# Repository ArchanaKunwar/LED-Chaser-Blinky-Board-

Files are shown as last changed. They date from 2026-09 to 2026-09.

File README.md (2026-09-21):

# Blinky Board (555 LED Chaser)

my first ever PCB!! its a little board with 10 LEDs that chase each other in a loop, and theres a knob on it so you can change how fast they go. thats it. thats the whole thing. but it works and honestly im so proud of it.

built this for Hack Club Half-life and i went in knowing basically nothing about PCB design so if i can do it you definately can.

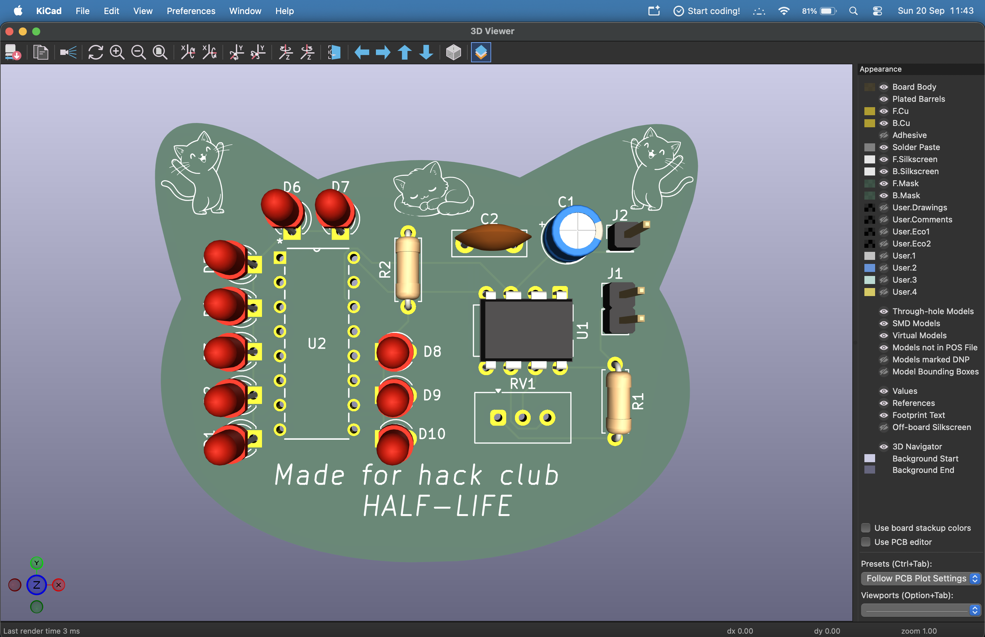
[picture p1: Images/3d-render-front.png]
finished board with LEDs chasing


---

## how it works
 
NE555 runs in astable mode and just oscillates forever, the speed depends on R1, C1 and the pot. that clock feeds the CD4017 (a decade counter) which moves its output over by one every pulse, 0 through 9 then loops back. put an LED on each output and you get the chase effect.
 
all 10 LED cathodes share ONE 470Ω resistor to ground since only one LED is ever on at a time, so you dont need 10 separate ones. blue LEDs come out a bit dimmer tho cause of higher forward voltage.
 
4017 wiring: VDD to +5V, VSS/CLKEN/RESET to GND, CLK to the 555 output pin 3, Cout unused.

---

## Bill of Materials

19 components total, comes out to about **$5.09** in parts.

| Ref | Qty | Value | Footprint | Link | Unit | Total |
|-----|-----|---|---|---|---|---|
| C1 | 1 | 1 µF | Capacitor_THT:CP_Radial_D5.0mm_P2.00mm | [LCSC C43342](https://www.lcsc.com/product-detail/C43342.html) | $0.14 | $0.14 |
| C2 | 1 | 0.01 µF | Capacitor_THT:C_Disc_D7.5mm_W2.5mm_P5.00mm | [LCSC C454399](https://www.lcsc.com/product-detail/C454399.html) | $0.17 | $0.17 |
| D1-D10 | 10 | LED | LED_THT:LED_D3.0mm | [LCSC C264302](https://www.lcsc.com/product-detail/C264302.html) | $0.10 | $1.00 |
| J1 | 1 | Conn_01x02_Socket | PinHeader_1x02_P2.54mm_Vertical | [DigiKey 929500-01-02-RK](https://www.digikey.com/en/products/result?keywords=929500-01-02-RK) | $0.10 | $0.10 |
| J2 | 1 | Conn_01x01_Socket | PinHeader_1x01_P2.54mm_Vertical | [DigiKey PRPC001DAAN-RC](https://www.digikey.com/en/products/result?keywords=PRPC001DAAN-RC) | $0.05 | $0.05 |
| R1 | 1 | 1kΩ | R_Axial_DIN0207_L6.3mm_D2.5mm_P7.62mm_Horizontal | [DigiKey CFR-25JR-52-1K](https://www.digikey.com/en/products/detail/yageo/CFR-25JR-52-1K/11974) | $0.05 | $0.05 |
| R2 | 1 | 470Ω | R_Axial_DIN0207_L6.3mm_D2.5mm_P7.62mm_Horizontal | [DigiKey CFR-25JR-52-470R](https://www.digikey.com/en/products/detail/yageo/CFR-25JR-52-470R/11966) | $0.05 | $0.05 |
| RV1 | 1 | 50kΩ | Potentiometer_Vishay_T93YA_Vertical | [LCSC C7061697](https://www.lcsc.com/product-detail/Trimmer-Potentiometers_VISHAY-T93YA503KT20_C7061697.html) | $1.58 | $1.58 |
| U1 | 1 | NE555P | DIP-8_W7.62mm | [LCSC C46749](https://www.lcsc.com/product-detail/Timers-Clocks_NE555P_C46749.html) | $0.56 | $0.56 |
| U2 | 1 | CD4017BE | N16 (DIP-16) | [LCSC C34519](https://www.lcsc.com/product-detail/Counters-Dividers_TI-CD4017BE_C34519.html) | $1.39 | $1.39 |

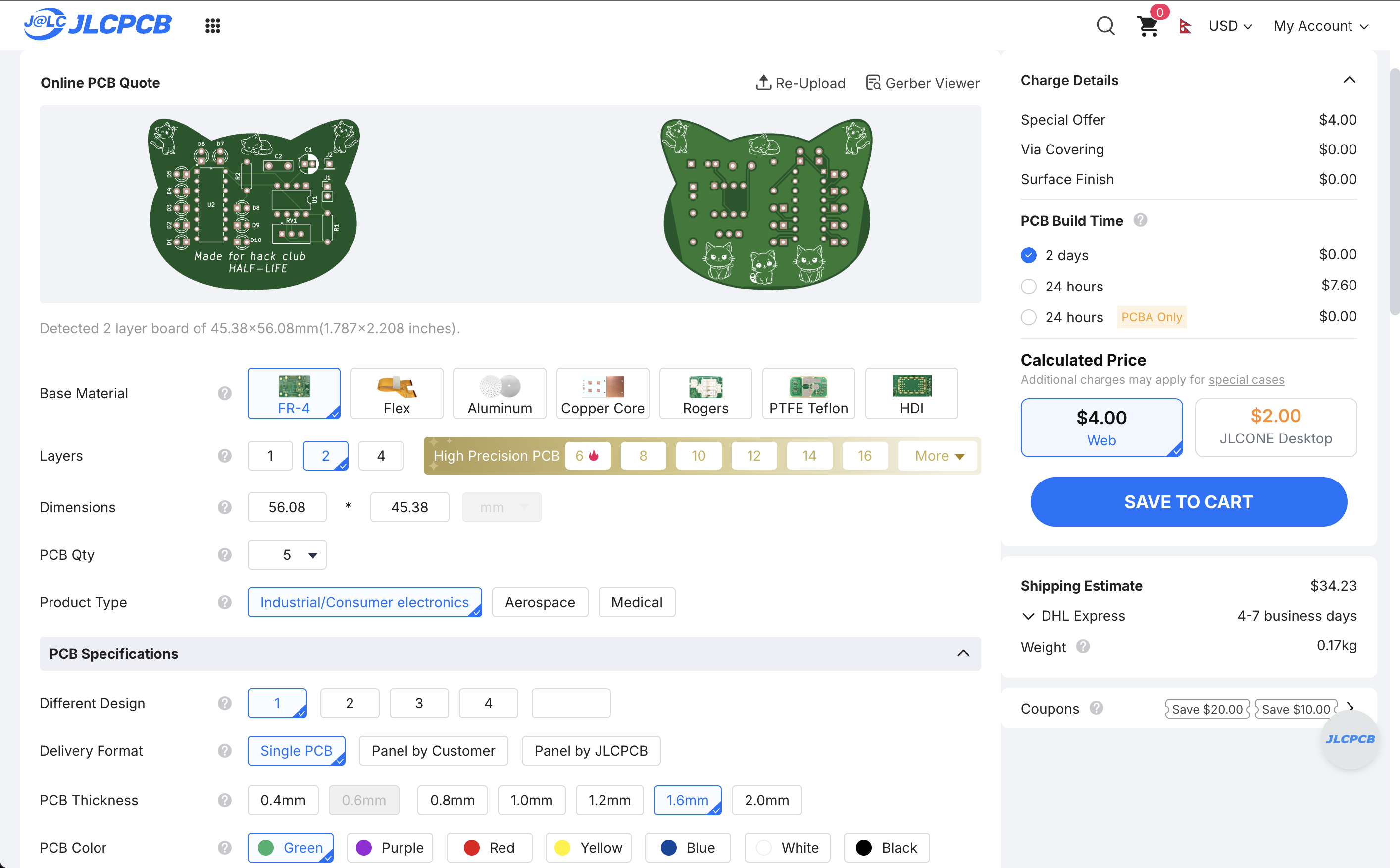
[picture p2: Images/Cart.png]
Cart


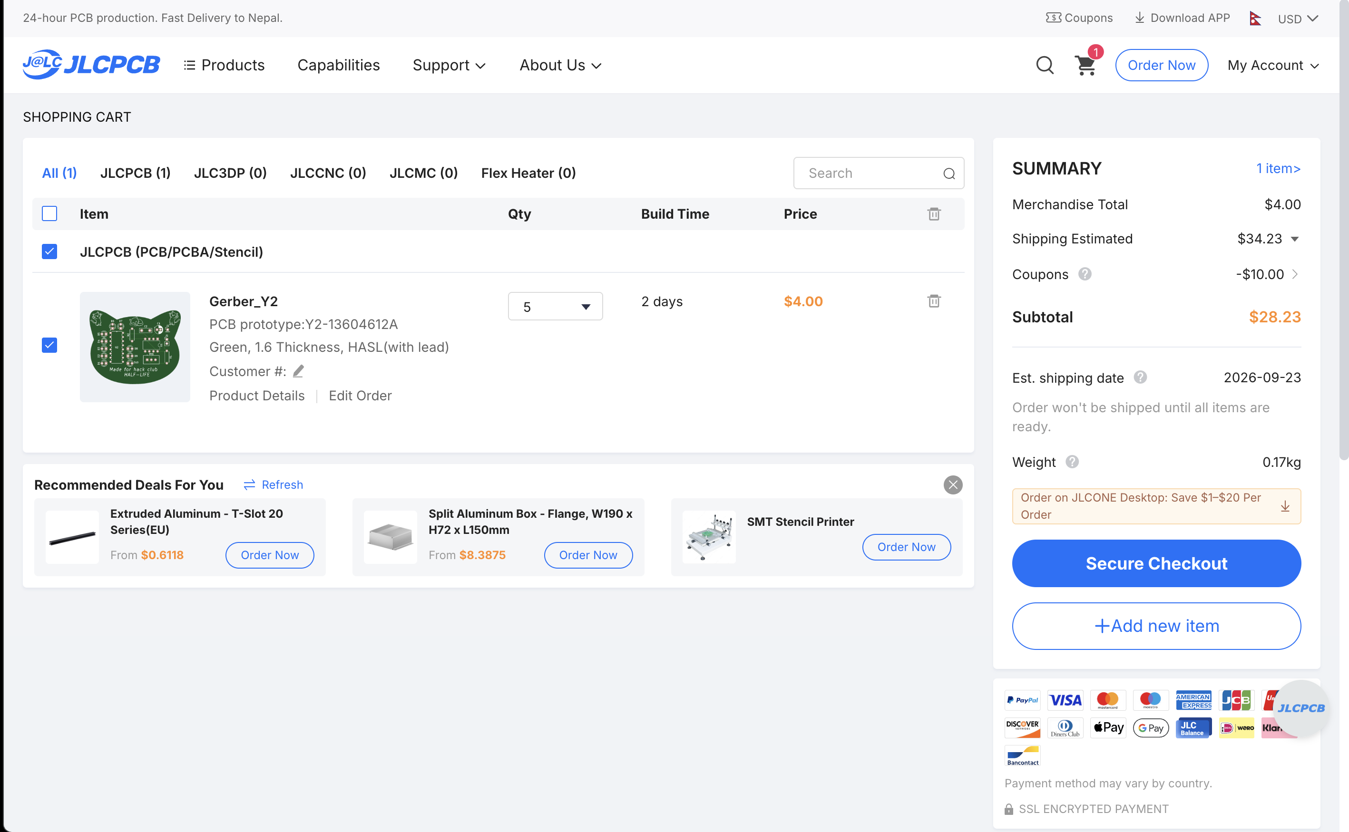
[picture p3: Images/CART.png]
Cart


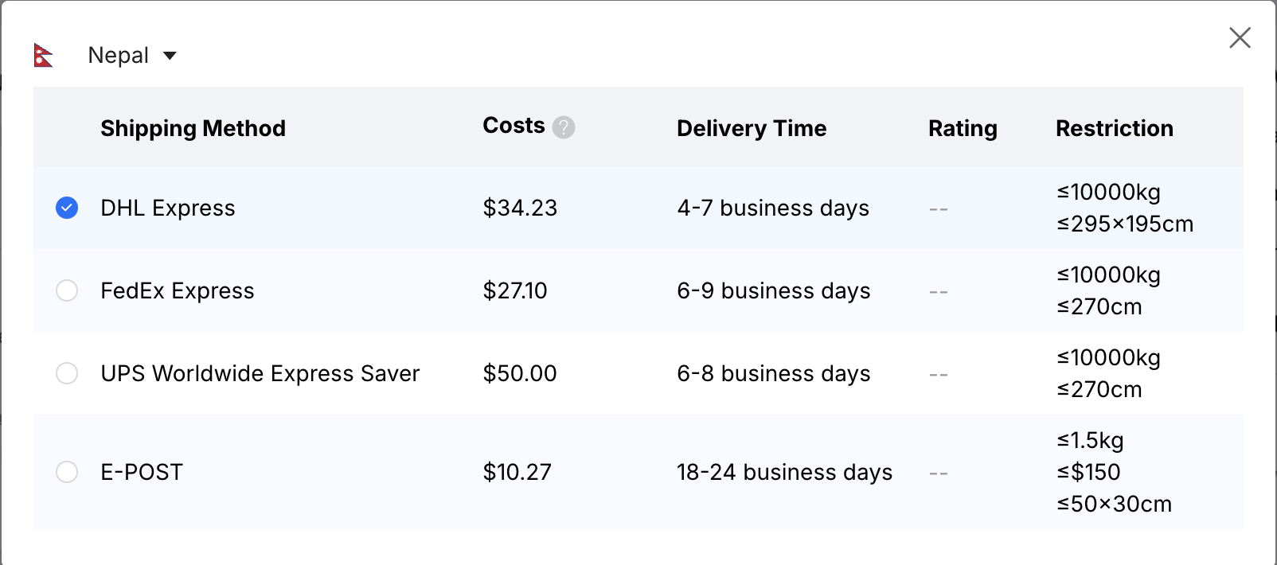
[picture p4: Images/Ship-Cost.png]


### cost breakdown

| Part | Cost |
|---|---|
| Component BOM | $5.09 |
| JLCPCB order after coupon| $28.23 |
| **parts + PCB** | **$33.32** |

---

## how to build it

1. order the PCB from JLCPCB using the gerbers in this repo. standard green, 1.6mm, default everything. 5 boards is the minimum
2. order the parts from the links above
3. solder the low stuff first (resistors, then the IC sockets or ICs, then caps, then LEDs, pot last)
4. **WATCH YOUR POLARITY.** C1 is electrolytic so it has a + and a -, and all 10 LEDs have a direction too. the short leg is the cathode. i put one LED in backwards and desoldering it was genuinely worse then all the soldering combined
5. power it with 5V through J1
6. turn the pot and watch it go

if nothing lights up, check RESET and CLKEN are actually grounded, thats usually the problem.

---

## whats in this repo

- the KiCad project files (schematic + PCB)
- gerbers + drill files, ready to send to JLCPCB
- the BOM
- my build journal with all the screenshots and every mistake i made along the way
- images folder

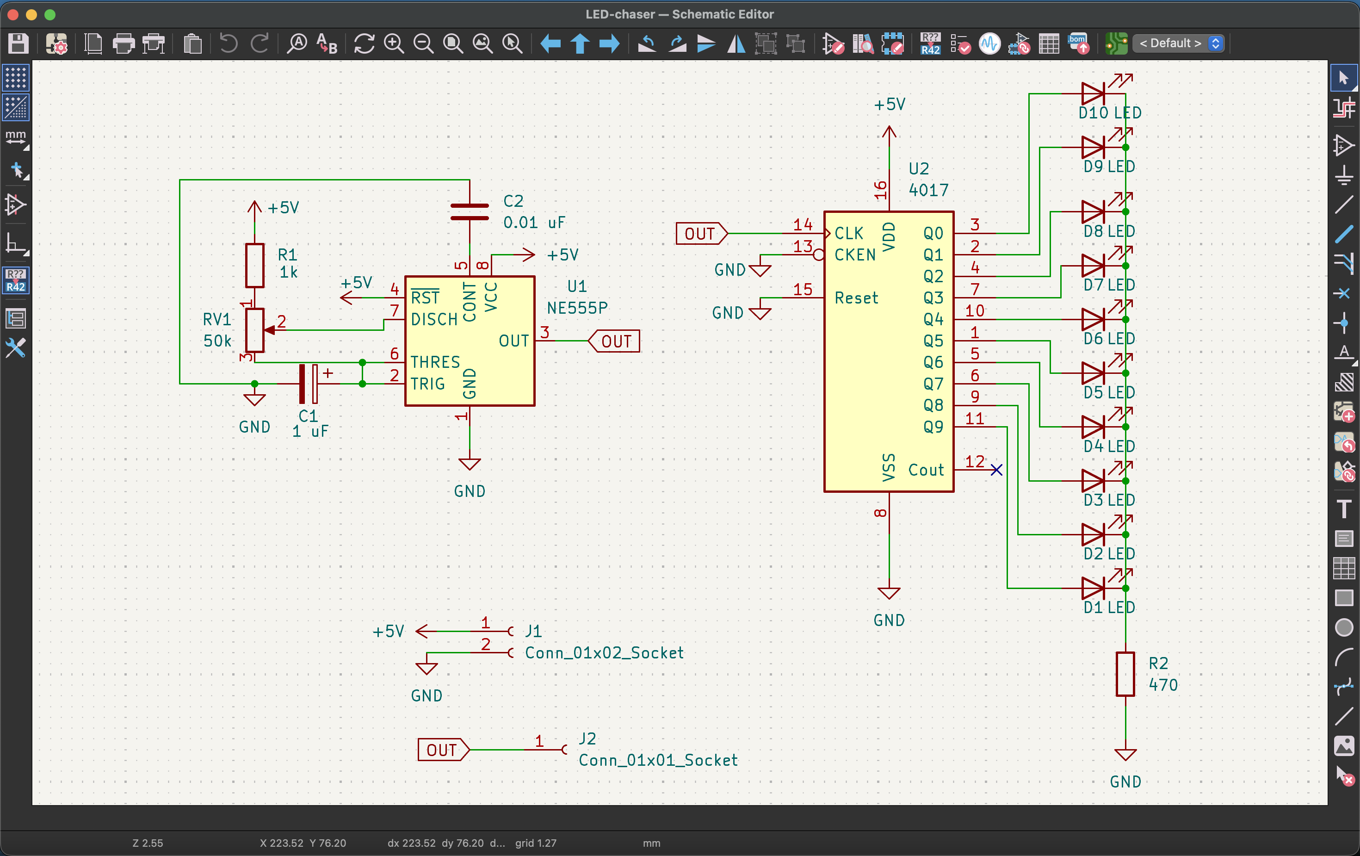
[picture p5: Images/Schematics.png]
full schematic

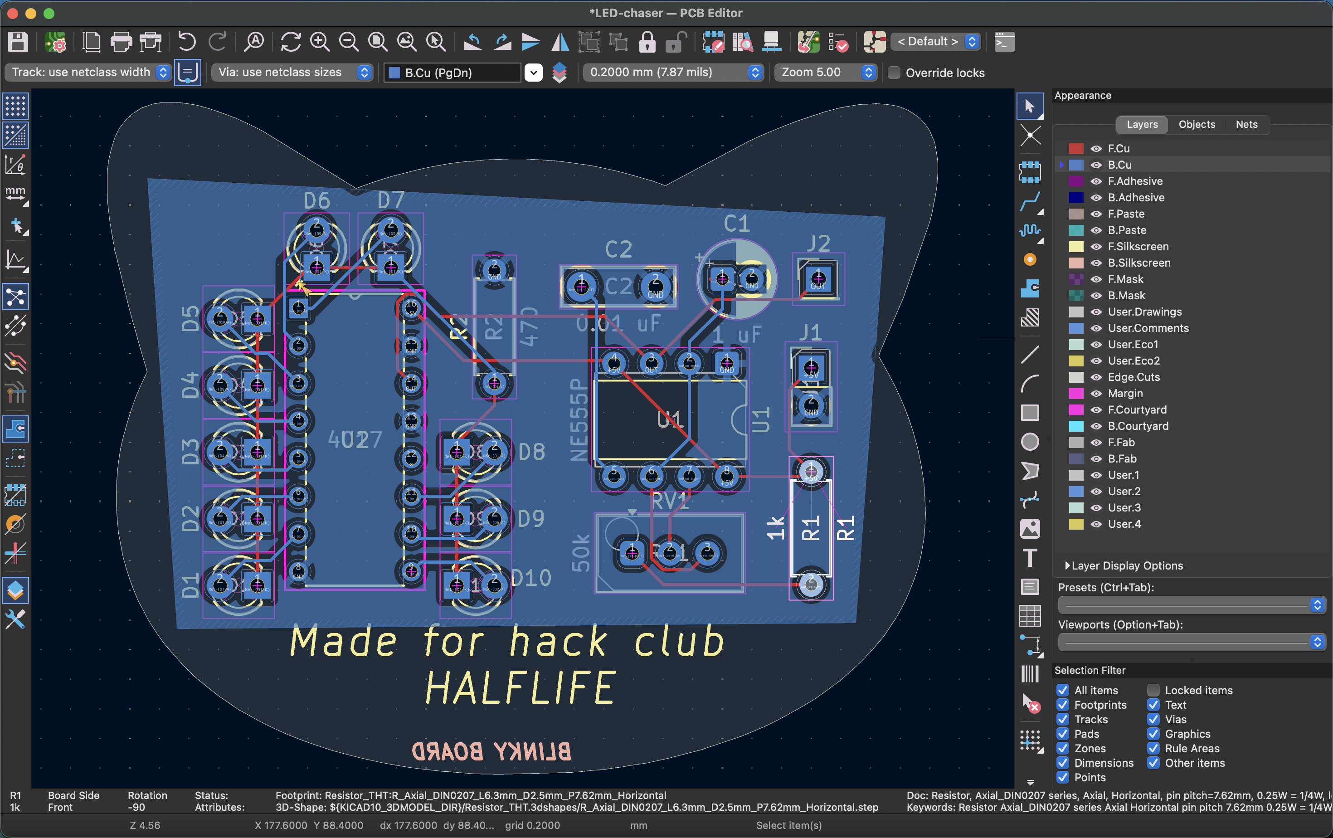
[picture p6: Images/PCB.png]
routed board

3D view
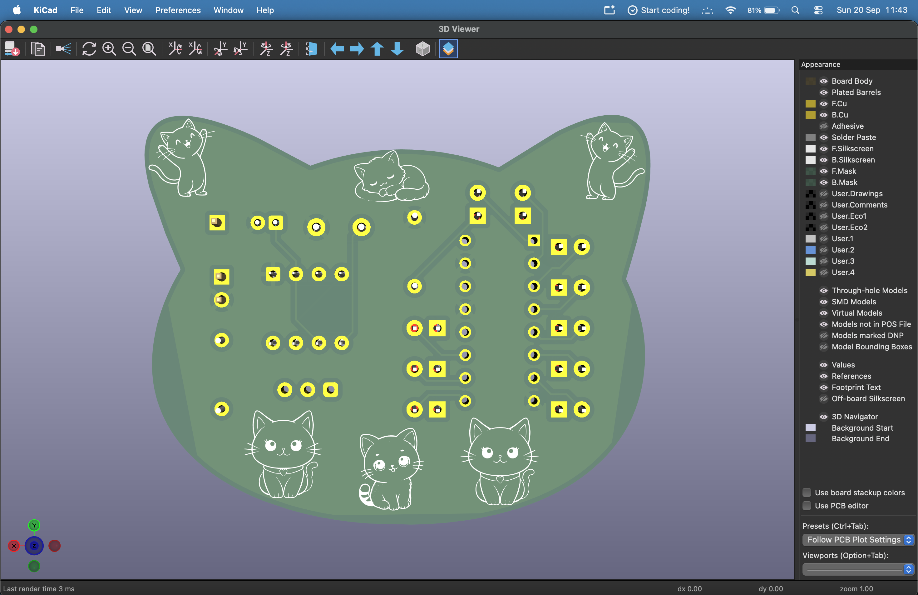
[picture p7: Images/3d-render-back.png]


---

## stuff i learned / things that went wrong

- the CD4017 footprint isnt in KiCad by default which is so annoying, had to grab it off Ultra Librarian and import it manually
- using labels instead of drawing wires everywhere made my schematic go from spaghetti to actually readable
- DRC hit me with like 15 errors the first time, mostly clearance stuff where traces were to close together. rerouted with more spacing and it cleaned up
- added a ground plane on the bottom layer, helps with noise and also just looks professional

## Made by
Archana Kunwar   
For hackclub

---

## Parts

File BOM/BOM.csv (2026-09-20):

Reference | Qty | Value | Footprint | Links | Est. Unit Price (USD) | Est. Total Price (USD)
C1 | 1 | 1 uF | Capacitor_THT:CP_Radial_D5.0mm_P2.00mm | https://www.lcsc.com/product-detail/C43342.html / https://www.lcsc.com/product-detail/C1579562.html | 0.14 | 0.14
C2 | 1 | 0.01 uF | Capacitor_THT:C_Disc_D7.5mm_W2.5mm_P5.00mm | https://www.lcsc.com/product-detail/C454399.html | 0.17 | 0.17
D1-D10 | 10 | LED | LED_THT:LED_D3.0mm | https://www.lcsc.com/product-detail/C264302.html / https://www.lcsc.com/product-detail/C99771.html | 0.1 | 1.0
J1 | 1 | Conn_01x02_Socket | Connector_PinHeader_2.54mm:PinHeader_1x02_P2.54mm_Vertical | https://www.digikey.com/en/products/result?keywords=929500-01-02-RK | 0.1 | 0.1
J2 | 1 | Conn_01x01_Socket | Connector_PinHeader_2.54mm:PinHeader_1x01_P2.54mm_Vertical | https://www.digikey.com/en/products/result?keywords=PRPC001DAAN-RC | 0.05 | 0.05
R1 | 1 | 1k | Resistor_THT:R_Axial_DIN0207_L6.3mm_D2.5mm_P7.62mm_Horizontal | https://www.digikey.com/en/products/detail/yageo/CFR-25JR-52-1K/11974 | 0.05 | 0.05
R2 | 1 | 470 | Resistor_THT:R_Axial_DIN0207_L6.3mm_D2.5mm_P7.62mm_Horizontal | https://www.digikey.com/en/products/detail/yageo/CFR-25JR-52-470R/11966 | 0.05 | 0.05
RV1 | 1 | 50k | Potentiometer_THT:Potentiometer_Vishay_T93YA_Vertical | https://www.lcsc.com/product-detail/Trimmer-Potentiometers_VISHAY-T93YA503KT20_C7061697.html / https://www.digikey.co.uk/en/products/detail/bourns-inc/3296W-1-503LF/1088059 | 1.58 | 1.58
U1 | 1 | NE555P | Package_DIP:DIP-8_W7.62mm | https://www.lcsc.com/product-detail/Timers-Clocks_NE555P_C46749.html | 0.56 | 0.56
U2 | 1 | 4017 | Package_DIP:DIP-16_W7.62mm | https://www.lcsc.com/product-detail/Counters-Dividers_TI-CD4017BE_C34519.html | 1.39 | 1.39
TOTAL | 19 |  |  |  |  | 5.09

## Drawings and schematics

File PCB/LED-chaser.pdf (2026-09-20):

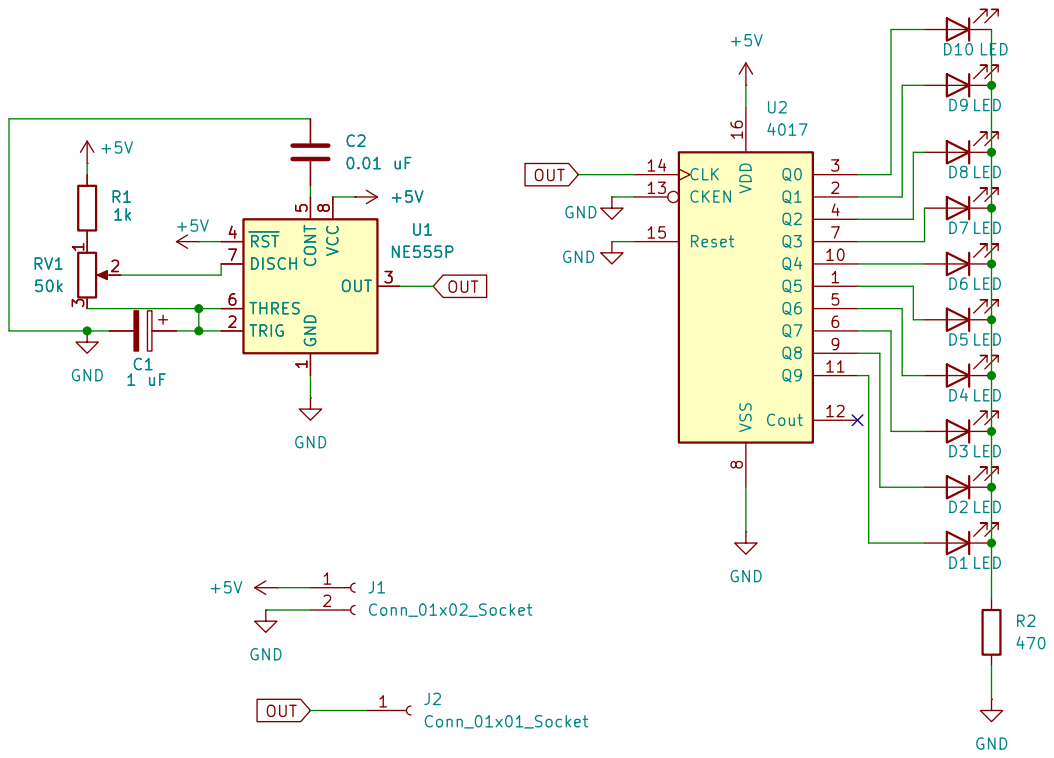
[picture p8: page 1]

8 Q8 9 Q4 10 Q9 11 Cout 12 CKEN 13 CLK 14 Reset 15 VDD 16 U2

Size: A4 | Rev:
KiCad E.D.A. 10.0.3 | Id: 1/1

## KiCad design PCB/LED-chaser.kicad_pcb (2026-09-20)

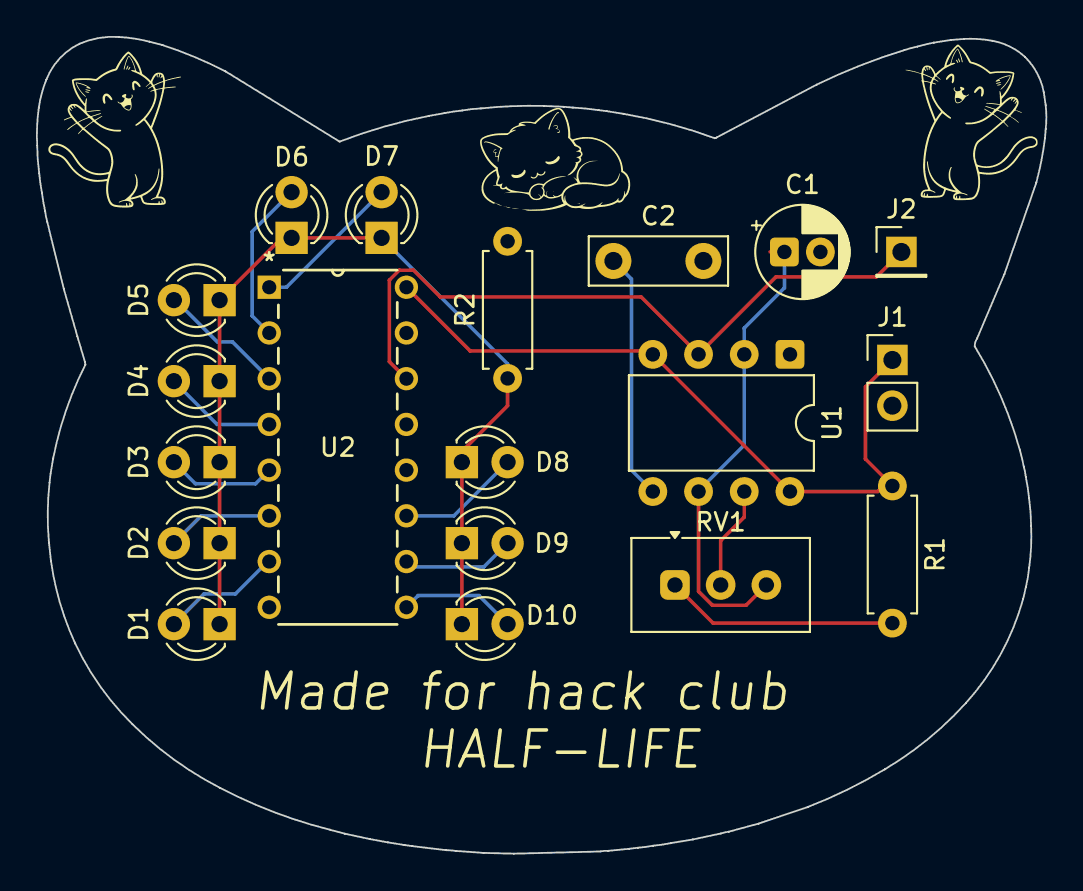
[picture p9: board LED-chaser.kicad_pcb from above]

Board: 2 copper layers, 56.1 x 45.4 mm, 19 parts (0 on the bottom side), 18 nets.

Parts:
C1: 1 uF; CP_Radial_D5.0mm_P2.00mm
C2: 0.01 uF; C_Disc_D7.5mm_W2.5mm_P5.00mm
D1, D2, D3, D4, D5, D6, D7, D8, D9, D10: LED; LED_D3.0mm
J1: Conn_01x02_Socket; PinHeader_1x02_P2.54mm_Vertical
J2: Conn_01x01_Socket; PinHeader_1x01_P2.54mm_Vertical
R1: 1k; R_Axial_DIN0207_L6.3mm_D2.5mm_P7.62mm_Horizontal
R2: 470; R_Axial_DIN0207_L6.3mm_D2.5mm_P7.62mm_Horizontal
RV1: 50k; Potentiometer_Vishay_T93YA_Vertical
U1: NE555P; DIP-8_W7.62mm
U2: 4017; N16

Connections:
+5V: J1.1, R1.1, U1.4 (~RST), U1.8 (VCC), U2.16 (VDD)
GND: C1.2, C2.2, J1.2, R2.2, U1.1 (GND), U2.8 (VSS), U2.13 (CKEN), U2.15 (Reset)
unnamed: D8.2 (A), U2.11 (Q9)
unnamed: D1.1 (K), D2.1 (K), D3.1 (K), D4.1 (K), D5.1 (K), D6.1 (K), D7.1 (K), D8.1 (K), D9.1 (K), D10.1 (K), R2.1
unnamed: D10.2 (A), U2.9 (Q8)
unnamed: D2.2 (A), U2.6 (Q7)
unnamed: D3.2 (A), U2.5 (Q6)
unnamed: D7.2 (A), U2.1 (Q5)
unnamed: D9.2 (A), U2.10 (Q4)
unnamed: D1.2 (A), U2.7 (Q3)
unnamed: D4.2 (A), U2.4 (Q2)
unnamed: D6.2 (A), U2.2 (Q1)
unnamed: D5.2 (A), U2.3 (Q0)
unnamed: R1.2, RV1.1
unnamed: C2.1, U1.5 (CONT)
unnamed: RV1.2, U1.7 (DISCH)
unnamed: C1.1, RV1.3, U1.2 (TRIG), U1.6 (THRES)
OUT: J2.1 (Pin_1_1), U1.3 (OUT), U2.14 (CLK)

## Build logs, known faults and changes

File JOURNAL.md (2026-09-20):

# Blinky Board (555 LED Chaser) Journal
 
---
 
## Entry 1 — Finally started, schematic done!!
 
ok so i finally opened KiCad after putting it off for like 3 days. ngl i was kinda intimidated but the guide made it pretty straightforward.
 
the plan is simple: 555 timer in astable mode = it just keeps oscillating forever, clocking the CD4017 counter. the 4017 then lights up 10 LEDs one at a time in sequence. pretty sick concept honestly.
 
### Stuff i placed
 
- **NE555P** — the timer
- **CD4017** — decade counter
- **1k resistor** — for the 555 timing
- **Potentiometer (RV)** — to control speed (this is the fun part, you can make it go zoom or snail pace)
- **100nF cap** — normal ceramic one
- **10uF electrolytic cap** — POLARIZED so direction matters!! almost messed this up
- **470Ω resistor** — shared by all LEDs
- **10 LEDs**

### Problems i hit
 
- pin names were confusing af at first. like why is it `CLKEN` and not just `CLK_EN`? took me a sec to figure out clock inhibit means "stop the clock" so we ground it
- wires were EVERYWHERE and it looked like spaghetti. switched to using labels instead and it looks way cleaner now
- the 555 astable config had me googling for like 20 mins. the capacitor goes between pin 2 and 6?? and then to ground?? eventually got it tho
### Screenshots

---



---



---
 
full schematic - it actually looks decent

---

**Time spent:** 3 hours (mostly googling tbh)
 
---

## Entry 2 — Footprints (this was kinda annoying)
 
assigned footprints to everything today. honestly this part was lowkey tedious but whatever.
 
### CD4017 footprint situation
 
so the guide said the CD4017 footprint isn't in KiCad by default which is actually so annoying?? like why wouldn't they include it. had to download from Ultra Librarian and import it. the import process was kinda confusing but i followed the guide step by step.  
 
footprint

checked pin spacing against the datasheet and everything seemed to line up. the 4017 is 2.54mm pitch which is standard for DIP so we good.
 
ran **Update PCB from Schematic** and everything showed up in the PCB editor in a big pile in the corner lol. 
 
### What went wrong
 
- spent like 30 mins confused about why my CD4017 symbol didn't have a footprint assigned. turns out i had to manually add it because it's not in the default library. dumb.

### Screenshots
 
assigning

assigning
 
**Time spent:** 1.5 hours
 
---

## Entry 3 — Board Outline, Routing + DRC (the struggle was real)
 
The guide is strict that the board needs a custom outline and custom art, so I spent a good chunk of this session on the shape. I used canva to make a cat head shaped designed and then I converted it to dxf using image to dxf converter. 

Then I placed the components inside the outline. What I learned:
- The thin blue lines are **ratlines**. They show which pads still need to connect.
- The goal is to move parts around so the ratlines are short and don't cross each other. This makes the routing later way easier.
- "r" rotates a part, and Ctrl+S is your friend. I saved every few minutes so I wouldn't lose progress.
ngl this part felt kinda like a puzzle. trying to fit everything without crossing lines too much. not perfect but it works.

ok so routing. this is where things got spicy.
 
routed the two-layer board with the "X" shortcut. used vias (V) when i had to switch to the back copper layer. honestly routing is kinda satisfying when it works but also infuriating when you get stuck.
 
### Ground plane situation
 
yes i added a ground plane on the bottom layer. the guide said it helps with noise and honestly it just looks professional. pressed "B" to fill it and everything.
 
### DRC errors
 
ran DRC and got like 15 errors initially  
 
- mostly clearance violations (traces too close to each other)
- a couple of unconnected items
- one via that was too close to a pad
fixed them by:
 
1. rerouting some traces with more spacing
2. moving that one via
3. re-running DRC like 5 times until it was clean
### Screenshots
 
Shape

PCB

PCB

3d render

3d render

3d render

3d render
 
**Time spent:** 4 hours (routing is pain)
 
---

## Entry 4 - Adding art in my pcb

I had sent the PCB image in the half-life channel and shadow gave suggestions to add arts in the pcb so I added some cute cat images.

3d render

3d render

3d render

**Time spent:** 1 hours (routing is pain)

---

---
 
## Entry 5 - readme and submission
 
added some custom art on the silkscreen. nothing crazy, just some text and a little lightning bolt because... blinky board... electricity... get it. also put my github handle on there so people know who made it.
 
then i exported everything:
 
- 3D view screenshot
- gerbers + drill files
- pushed all the .kicad files to github
- wrote a README (no AI i promise, wrote it myself)
got a JLCPCB quote for 5 boards in standard green.

3d render

**time spent:** 0.5 hours
 
---

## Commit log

2026-09-19 Pcb images
2026-09-20 Added the pcb files
    [LED-chaser.kicad_pcb, LED-chaser.kicad_sch]
2026-09-20 Schematics pdf
2026-09-20 Gerber Files
    [LED-chaser-B_Cu.gbr, LED-chaser-B_Mask.gbr, LED-chaser-B_Paste.gbr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]
2026-09-20 Drill files
    [LED-chaser-NPTH.drl, LED-chaser-PTH.drl]
2026-09-20 BOM files
    [BOM.csv]
